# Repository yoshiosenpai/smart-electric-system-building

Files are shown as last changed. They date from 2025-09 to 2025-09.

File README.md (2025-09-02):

# Smart Electric System in Building (ESP32 + Blynk, 4× AC Bulbs, Manual Buttons)

This project demonstrates controlling **4 AC light bulbs wirelessly** using an **ESP32** and the **Blynk** app, plus **manual buttons** for local control.  
Built as a **Final Year Project (FYP) prototype** on a **wooden board**.

> ⚠️ **Prototype Only.** Not for permanent household use. Handle AC wiring with proper insulation, fuse protection, and supervision.

---

## 1) Project Overview
- **Objective:** Wi-Fi app control + **manual buttons** (like wall switches) on a demo board.
- **Core Idea:** ESP32 receives commands from Blynk **or** local button press → drives relays → toggles AC bulbs.
- **Outcome:** Two-way control with a single source of truth (ESP32 logic keeps app and buttons in sync).

---

## 2) Hardware 
1. ESP32 with expansion board  
2. 4-CH Active H/L 5V Relay Module (opto-isolated, 10A @ 250VAC)  
3. 5V 2A DC adapter  
4. LED E27 bulbs (5–10W recommended) ×4  
5. E27 bulb holders ×4  
6. **Momentary push buttons (NO)** ×4 (22mm panel type) 
7. Inline fuse (2–3A, slow blow) + fuse holder  
8. Terminal blocks, hookup wires, labels, cable ties  
9. Wooden mounting board

---

## 3) Methodology
ESP32 runs a **logic switch** model: both the **Blynk app** and **local buttons** request state changes; ESP32 **owns the ground truth** and updates **relays** and **Blynk UI** accordingly.

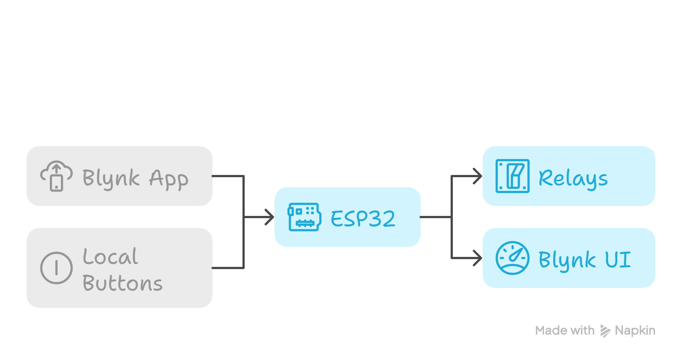
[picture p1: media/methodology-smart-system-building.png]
methodology


---

## 4) Technique & Procedure
1. **Blynk Setup**
   - Create a device/template and 4 **Switch** widgets bound to **V0–V3** (0/1).
2. **Wiring (Low Voltage)**
   - ESP32 GPIO16..19 → Relay IN1..IN4  
   - **Buttons (momentary NO)**: one side → ESP32 GPIO (e.g., 21/22/23/25), other side → **GND** (use `INPUT_PULLUP`).
   - Share **GND** between ESP32, relay board, and 5V adapter.
3. **Wiring (Mains)**
   - **Live** → **Fuse** → Relay **COM1..COM4** (bridged).  
   - Relay **NO1..NO4** → Bulbs **Live**.  
   - **Neutral** → common neutral bus to bulbs.
4. **Firmware**
   - On Blynk `V0–V3` write → set state, drive relay, reflect to app.
   - On **button press** → **toggle** channel state (debounced), drive relay, reflect to app.
5. **Demo Assembly**
   - Mount parts on wooden board; route AC and DC on **separate lanes**; add big **CAUTION** label.
   - Test one channel at a time, then full system.

---

## 5) Estimated Cost (MYR, prototype)
| Item | Qty | Unit (RM) | Subtotal (RM) |
|---|-----|---|---|
| ESP32 + Expansion Bd. | 1 | 40 | 40 |
| 4-CH Relay Module | 1 | 13 | 13 |
| 5V/2A Adapter | 1 | 14 | 14 |
| LED Bulbs (5–10W) | 4 | 7 | 28 |
| Bulb Holders | 4 | 7 | 28 |
| Momentary Buttons (NO)| 4 | 6 | 24 |
| Fuse + Holder | 1 | 26 | 26 |
| Wires, board, misc. | — | 30 | 30 |
| **Total (approx.)** | | | **204** |

---

## 6) Specifications
- **Controller:** ESP32 (Wi-Fi, Blynk IoT)  
- **Manual Control:** 4× momentary NO buttons (GPIO with `INPUT_PULLUP`)  
- **Relays:** 4 channels, opto-isolated, 10A @ 250VAC (mechanical)  
- **Loads:** 4× LED bulbs (5–10W each)  
- **Power:** 5V 2A DC adapter (ESP32 + relay coils)  
- **Prototype:** Wooden board mounting with labeled channels and safety fuse

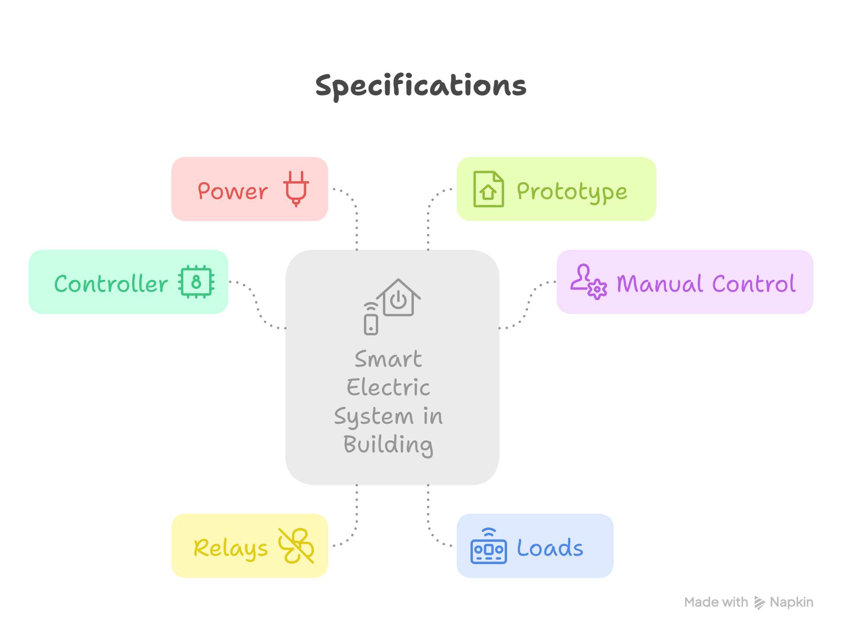
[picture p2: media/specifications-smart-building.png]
Specifications


---

## 7) Wiring Tables

### 7.1 Low-Voltage (ESP32, Buttons, Relays, 5V)
| Component | Pin / Terminal  | Connects To | Notes |
|---|---|---|---|
| ESP32 | 5V / VIN | Relay VCC & 5V adapter +  | Power to relay board |
| ESP32 | GND | Relay GND & 5V adapter –  | Common ground |
| ESP32 | GPIO16 | Relay IN1 | Channel 1 control |
| ESP32 | GPIO17 | Relay IN2 | Channel 2 control |
| ESP32 | GPIO18 | Relay IN3 | Channel 3 control |
| ESP32 | GPIO19 | Relay IN4 | Channel 4 control |
| Button 1 (NO) | One leg | ESP32 **GPIO21** | Set `INPUT_PULLUP` |
| | Other leg | ESP32 **GND** | Press → LOW |
| Button 2 (NO) | One leg | ESP32 **GPIO22** | 〃 |
| | Other leg | ESP32 **GND** | 〃 |
| Button 3 (NO) | One leg | ESP32 **GPIO23** | 〃 |
| | Other leg | ESP32 **GND** | 〃 |
| Button 4 (NO) | One leg | ESP32 **GPIO25** | 〃 |
| | Other leg | ESP32 **GND** | 〃 |

### 7.2 Mains (Fuse, Relays, Bulbs)
| Component | Pin / Terminal | Connects To | Notes  |
|---|---|---|---|
| AC **Live** | — | **Fuse** → Relay **COM1–4**  | Bridge COM1–COM4 after fuse |
| Relay CH1 | **NO1** | Bulb 1 **Live** | Switched live |
| Relay CH2 | **NO2** | Bulb 2 **Live** | 〃 |
| Relay CH3 | **NO3** | Bulb 3 **Live** | 〃 |
| Relay CH4 | **NO4** | Bulb 4 **Live** | 〃 |
| AC **Neutral** | — | Bulbs Neutral (common bus) | Direct |
| Earth (if any) | — | As required by fixtures | Safety/metal parts |

---

## 8) How It Works
1. ESP32 boots, connects to Wi-Fi and Blynk.  
2. **Blynk Switch (V0–V3)** or **Button press** requests a channel toggle.  
3. ESP32 updates the **channel state**, drives the **relay**, and **reflects state** back to the Blynk UI.  
4. Bulbs turn ON/OFF via **NO** contacts switching the **Live** conductor.

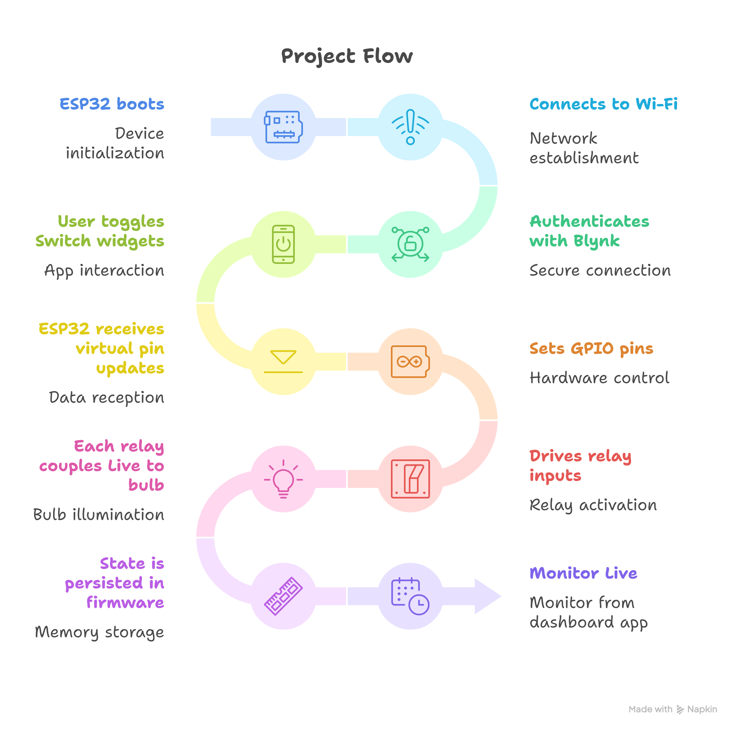
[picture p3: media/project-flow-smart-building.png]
Project-Flow


---

## 9) Firmware Scaffold
- Configure pins: `RELAY[4] = {16,17,18,19}`, `BUTTON[4] = {21,22,23,25}`  
- Set buttons `INPUT_PULLUP`, debounce ~100–150 ms  
- On Blynk write → set state + drive relay + `virtualWrite()`  
- On button press → **toggle** state + drive relay + `virtualWrite()`  
(See `/firmware/main.cpp` for the full example.)

---

## 10) Safety Checklist
- **Inline fuse** on Live before relay COM bridge.  
- Keep AC and DC physically separated on the board.  
- Use terminal blocks/heatshrink for all mains joints.  
- Label channels and add a visible **CAUTION: 230V/120V AC** sign.  
- Never touch the board while powered.

---

## 11) License
Licensed under the **MIT License** — see [`LICENSE`](./LICENSE).

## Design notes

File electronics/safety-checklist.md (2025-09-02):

# Safety Checklist — Smart Electric System (FYP Prototype on Wooden Board)

> ⚠️ **DANGER: MAINS VOLTAGE (230 VAC / 120 VAC).** This prototype is for demonstration only and is **not** a certified household installation. Work under supervision, use proper tools/PPE, and never touch the board while energized.

## 0) Scope & Assumptions
- Use case: ESP32 controls 4 relays to switch LED bulbs (5–10 W each).
- Mounting: Exposed components on a **wooden board** with clear AC vs DC lanes.
- Architecture: **Option A (logic switch)** — momentary buttons to ESP32 GPIO; no mains switching by the buttons.

---

## 1) Personal Protective Equipment (PPE)
- [ ] Safety glasses
- [ ] Insulated screwdrivers
- [ ] Closed shoes, no metal jewelry/watches
- [ ] One-hand rule when probing live (keep other hand away)

---

## 2) Standards & Good Practice (Educational Context)
- [ ] **RCD/GFCI** (residual current device) protected outlet used for demos
- [ ] **Labeling**: “⚠️ MAINS VOLTAGE — DEMO ONLY” clearly visible
- [ ] **Supervision**: A qualified person reviews the wiring before first power-up

---

## 3) Parts Ratings & Selection
- [ ] Relay module rated **≥10 A @ 250 VAC**, opto-isolated inputs
- [ ] LED bulbs **≤10 W** each, non-smart (low inrush)
- [ ] Inline **fuse** on Live input: **2–3 A slow-blow** (for 4× LED bulbs)
- [ ] **Mains wire**: min **0.75 mm²** (≈ AWG 18) copper, heat-resistant insulation
- [ ] Low-voltage wires: properly sized, flexible, not frayed
- [ ] Power adapter: **5 V / 2 A** minimum, reputable brand

---

## 4) Layout & Segregation (Board Build)
- [ ] **Separate lanes**: AC on one side, DC/logic on the other (clear visual gap)
- [ ] Keep **≥10 mm** clearance between AC and DC runs (no crossovers)
- [ ] Relay board mounted so **AC terminals face AC lane**, **logic pins face DC lane**
- [ ] Cable management: clips/zip ties; no loose loops near hot parts
- [ ] Heat sources (bulbs, resistors) away from plastic or wood edges

---

## 5) Wiring Rules (Color, Termination, Strain Relief)
- [ ] **Color code**: Brown=Live, Blue=Neutral, Green/Yellow=Earth (or local standard)
- [ ] **Live path**: Wall → **Fuse** → Bridge to **COM1–COM4** → **NO1–NO4** → Bulb Lives
- [ ] **Neutral**: Direct neutral bus to all bulbs (never through relay)
- [ ] **Earth**: Pass through to any earthed metal parts/sockets (if used)
- [ ] All AC joints via **barrier terminal blocks** (no twisted/bare joins)
- [ ] Heatshrink or insulated ferrules on exposed conductors
- [ ] **Strain relief** on mains inlet (gland or clamp)

---

## 6) Low-Voltage (ESP32, Buttons, Relay Inputs)
- [ ] Common **GND** between ESP32, relay board, and 5 V adapter
- [ ] ESP32 → Relay IN1..IN4: short, tidy, not bundled with AC
- [ ] Buttons: **momentary NO**; one leg to GPIO (21/22/23/25), other to **GND**
- [ ] Firmware uses `INPUT_PULLUP`; press = **LOW**
- [ ] No low-voltage wire runs under AC terminals

---

## 7) Pre-Power Electrical Checks (Multimeter)
- **Continuity (power OFF, unplugged):**
  - [ ] **Live** does **not** short to **Neutral** or **Earth**
  - [ ] **ESP32 GND** has no continuity to AC Live/Neutral/Earth
- **Polarity:**
  - [ ] Fuse is on **Live** only (not on Neutral)
  - [ ] COMs are bridged **after** the fuse (not before)
- **Relay logic:**
  - [ ] With ESP32 unpowered, **NO** contacts are open (bulbs cannot energize)

---

## 8) First Power-On (Low Voltage Only)
- [ ] Power **5 V adapter** only; ESP32 boots
- [ ] Blynk connects; toggling V0–V3 moves **only** relay LEDs/clicks
- [ ] Buttons toggle channels once (no chatter); serial logs OK
- [ ] No unexpected heating or smell at relay board

---

## 9) Mains Bring-Up (Stepwise)
- [ ] Connect **one** bulb to CH1; verify wiring again
- [ ] Power mains via **RCD/GFCI** extension
- [ ] Toggle CH1: bulb ON/OFF cleanly; no flicker
- [ ] Measure current (optional) — consistent with bulb rating
- [ ] Repeat for CH2–CH4 one at a time, then all together
- [ ] 15–30 min **soak test** with all ON: relay area <~**60 °C** (touch-safe guideline)

---

## 10) Functional Safety Behaviors
- [ ] **Default OFF** at boot (all relays inactive)
- [ ] **Loss of Wi-Fi**: buttons still work; no random toggles
- [ ] **Recovery**: Blynk sync updates UI to current states
- [ ] **Emergency stop**: mains plug accessible, RCD test button known

---

## 11) What **Not** To Do
- [ ] Do **not** leave prototype powered **unattended**
- [ ] Do **not** expose **bare AC** terminals (always use barrier blocks/heatshrink)
- [ ] Do **not** route AC over/under the ESP32 or logic area
- [ ] Do **not** let wires rest on hot bulbs/lamps

---

## 12) Documentation Photos (for FYP Report)
- [ ] Full board photo with AC vs DC lanes labeled
- [ ] Close-ups: fuse placement, terminal blocks, relay outputs
- [ ] Wiring diagram/table included in README
- [ ] Short demo: button press → bulb ON/OFF; app sync

---

## 13) Sign-off (Before Public Demo)
| Item | Pass/Fail | Initials | Date |
|---|---|---|---|
| PPE & RCD in place | | | |
| AC/DC segregation & labeling | | | |
| Fuse on Live; polarity correct | | | |
| No exposed live parts | | | |
| Low-voltage tests passed | | | |
| Single-channel AC test passed | | | |
| Four-channel AC test passed | | | |
| 30-min soak test passed | | | |

---

## 14) Risk Snapshot (Top Hazards & Mitigations)
- **Electric shock (contact with live parts)** → Barrier terminals, heatshrink, RCD, clear labels, supervision  
- **Short circuit / overheating** → Inline fuse on Live, correct wire gauge, tidy routing, soak test  
- **Logic/AC cross-talk** → 10+ mm clearance, no shared bundles, opto-isolated relays  
- **Operational misuse** → Default-OFF at boot, emergency unplug accessible, demo script rehearsed

---

**Reminder:** This checklist supports educational safety. It does **not** replace national electrical codes or compliance standards.

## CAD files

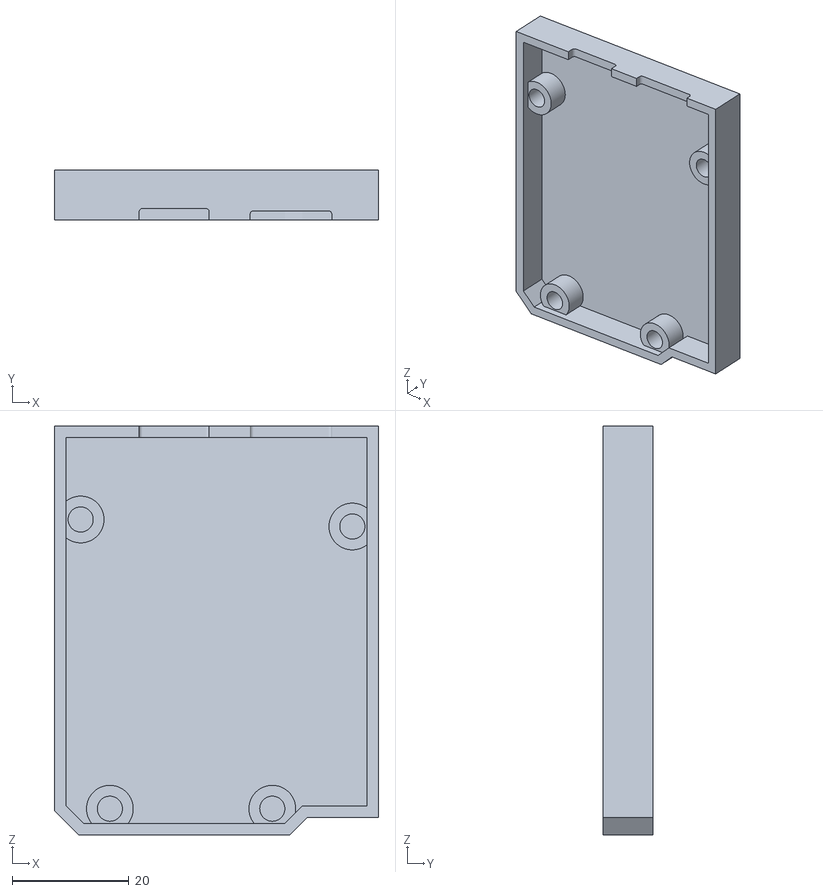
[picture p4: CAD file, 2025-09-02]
hardware/ESP32_Adapter-Base.stl
55.5 x 8.60 x 70.0

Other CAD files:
hardware/ESP32_Adapter-Base_A.stl
hardware/ESP32_Adapter_A.FCStd
hardware/ESP32_Adapter.FCStd

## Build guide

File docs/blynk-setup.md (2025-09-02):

# Blynk Setup (ESP32 + 4 Channels)

This guide links your ESP32 to the Blynk app, with 4 virtual switches (V0–V3) that control 4 relays. It matches the Arduino sketch in this repo.

---

## 1) Create Template & Device (Blynk Console)
1. Sign in to **Blynk Console** (web).
2. **Create Template**
   - Template Name: `Smart Electric System`
   - Hardware: `ESP32`
   - Connection: `WiFi`
3. **Create Datastreams (4x)**
   - For each `V0`, `V1`, `V2`, `V3`:
     - **Type:** Virtual Pin  
     - **Data Type:** Integer  
     - **Min/Max:** 0 / 1  
     - **Default:** 0  
     - **Permissions:** Read & Write  
4. **Save** the template.
5. **Create Device** from this template (assign it to your account).

> Grab these from **Device Info**:  
> - `BLYNK_TEMPLATE_ID`  
> - `BLYNK_TEMPLATE_NAME` (optional for display)  
> - `BLYNK_AUTH_TOKEN`  
> Put them in your Arduino sketch.

---

## 2) Build the Mobile Dashboard (Blynk App)
1. Open the **Blynk mobile app** → log in with the same account.
2. Your device should appear; open it.
3. Add **4 × Switch** widgets:
   - Switch #1 → Datastream `V0`
   - Switch #2 → Datastream `V1`
   - Switch #3 → Datastream `V2`
   - Switch #4 → Datastream `V3`
4. (Optional) Add **Labels** like “Bulb 1…4”.

---

## 3) Matching the Arduino Sketch
The provided sketch expects:
- **Relays:** GPIO `16/17/18/19` → Relay `IN1..IN4`
- **Buttons (momentary NO):** GPIO `21/22/23/25` → GND (use `INPUT_PULLUP`)
- **Virtual pins:** `V0..V3`
- **Active-LOW relays:** `RELAY_ACTIVE_LOW = true` (flip if your board is active-HIGH)

On connection, the code does:
```cpp
Blynk.syncVirtual(V0, V1, V2, V3);

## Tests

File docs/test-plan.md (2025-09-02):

# Test Plan — Smart Electric System (ESP32 + Blynk + Buttons)

Scope: Verify Option-A logic (ESP32 as source of truth), safety basics, and demo readiness on a wooden board.

---

## 1) Test Environment
- Low-voltage: ESP32 + 4-ch relay board + 5V/2A adapter
- Inputs: 4 × momentary NO buttons (to GND)
- Loads: 4 × LED bulbs (5–10 W), E27 holders
- AC: Fused Live → Relay COM bridge; NO → Bulb Lives; Neutral bus
- Tools: Serial Monitor (115200), multimeter (voltage/current), timer/stopwatch
- Network: 2.4 GHz Wi-Fi or phone hotspot

---

## 2) Acceptance Criteria (summary)
- **Connectivity:** ESP32 connects to Wi-Fi & Blynk within 30 s.
- **Control:** Each channel toggles via **App** and **Button**; update reflected in both within 300 ms.
- **Default State:** On power-up, all channels **OFF** (relays inactive) until commanded.
- **Debounce:** Single press → single toggle (no chatter).
- **Safety:** Fuse inline on Live; AC and DC wiring clearly separated and insulated.
- **Soak:** 30-minute ON test: no excessive heating or intermittent behavior.

---

## 3) Functional Tests

### 3.1 Low-Voltage Bring-Up
| Step | Action | Expected |
|-----:|---|---|
| 1 | Power ESP32 + relays only (no AC) | Board powers; no relays latched |
| 2 | Open Serial Monitor | Wi-Fi + Blynk connect messages |
| 3 | Press Button 1 | Serial shows `[CH1] -> ON/OFF`; Relay 1 clicks |
| 4 | Toggle V0 in app | Relay 1 clicks; Serial reflects state; app mirrors |
| 5 | Repeat for CH2–CH4 | All pass |

### 3.2 App–Button Consistency
| Step | Action | Expected |
|-----:|---|---|
| 1 | Turn CH1 ON in app | Relay ON; app shows ON |
| 2 | Press Button 1 once | Relay toggles OFF; app flips to OFF |
| 3 | Press Button 1 twice (slow) | Two toggles; app matches each |
| 4 | Long-press Button 1 | **One** toggle only (debounce ok) |

### 3.3 Power Cycle Behavior
| Step | Action | Expected |
|-----:|---|---|
| 1 | Set CH1=ON, CH2=OFF, CH3=ON, CH4=OFF | States set |
| 2 | Power cycle ESP32 | All relays default **OFF** at boot |
| 3 | After Blynk connect | `syncVirtual` aligns app and device (device keeps OFF until commanded) |

> Note: This prototype defaults **OFF** for safety. Document this in your report.

---

## 4) High-Voltage (AC) Tests — With Caution
**Pre-check:** Fuse installed; terminals insulated; clear AC/DC separation; supervisor present.

### 4.1 Single-Channel AC Test
| Step | Action | Expected |
|-----:|---|---|
| 1 | Wire CH1 only to bulb | Wiring checked |
| 2 | Apply AC | No sparks/smell; bulb OFF |
| 3 | Toggle V0 (or Button 1) | Bulb ON/OFF cleanly; no flicker |
| 4 | Measure current | Matches bulb rating; relay coil still cool |

### 4.2 Four-Channel AC Test
| Step | Action | Expected |
|-----:|---|---|
| 1 | Wire all 4 bulbs | Wiring checked |
| 2 | Turn all ON | All bulbs ON; adapter/relays stable |
| 3 | Turn all OFF | All bulbs OFF |

---

## 5) Soak & Thermal
- **Test:** Keep all four bulbs ON for **30 minutes**.
- **Observe:** No random toggles; relay board temperature acceptable (coil area ideally < ~60 °C).  
- **Record:** Ambient temp, any anomalies.

---

## 6) Network Resilience
| Step | Action | Expected |
|-----:|---|---|
| 1 | Disconnect Wi-Fi/hotspot | App shows offline; **buttons still work** |
| 2 | Reconnect Wi-Fi | Device reconnects; app syncs to current states within a few seconds |

---

## 7) Documentation Artifacts to Capture
- Photos of board layout (AC lane vs DC lane), fuse placement, labels
- Short video: Button press → app updates; App toggle → relay click → bulb ON
- Serial logs during tests (copy snippets)
- Cost table + final BOM links

---

## 8) Test Log Template

| Date | Tester | Test Case ID | Result (P/F) | Notes / Fixes |
|---|---|---|---|---|
| | | LV-01 | | |
| | | LV-02 | | |
| | | AC-01 | | |
| | | AC-02 | | |
| | | SOAK-01 | | |
| | | NET-01 | | |

---

## 9) Risks & Mitigations
- **Mains safety:** Always fuse Live; insulate joints; never touch while powered.  
- **Relay logic inverted:** Flip `RELAY_ACTIVE_LOW`.  
- **Button bounce:** Increase `DEBOUNCE_MS`.  
- **Wi-Fi drop:** Buttons still work; state sync on reconnect.

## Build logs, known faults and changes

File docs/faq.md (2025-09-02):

---

### `docs/faq.md`

```markdown
# FAQ — Smart Electric System (FYP Prototype)

## General
**Q: Is this safe for permanent home use?**  
A: No. This is a **demo prototype** on a wooden board. It is not certified for household installation.

**Q: Why do we use Blynk “Virtual Pins” instead of Digital Pins?**  
A: Virtual Pins decouple app UI from hardware pins, making sync and logic handling easier (e.g., buttons + app + debouncing).

---

## Connectivity
**Q: ESP32 won’t connect to Wi-Fi.**  
- Use **2.4 GHz** SSID (no 5 GHz).  
- Check SSID/PASS spelling; avoid special characters.  
- Try a phone hotspot for demo stability.

**Q: Blynk stays offline.**  
- Verify `BLYNK_AUTH_TOKEN`.  
- Log into the **same Blynk region** on Console and App.  
- Ensure the device is created from the **same template** with V0–V3.

---

## Relays & Buttons
**Q: Relays click ON when I expect OFF.**  
- Your module might be active-HIGH. Set `RELAY_ACTIVE_LOW = false;`

**Q: Buttons don’t toggle reliably.**  
- Confirm wiring: **GPIO ↔ Button ↔ GND**; use `INPUT_PULLUP`.  
- Increase debounce: `DEBOUNCE_MS` to 150–200 ms.

**Q: Why momentary (NO) buttons, not latching switches?**  
- With Option A, ESP32 is the “logic switch”. Momentary inputs produce clean events; firmware maintains the true state and syncs to Blynk.

---

## Power & Safety
**Q: What fuse rating should I use?**  
- Inline fuse on **Live**; typical **2–3 A slow-blow** for 4 × 5–10 W LED bulbs (low current). Adjust for your local mains and load.

**Q: The relay board gets warm. Is that normal?**  
- Mild warmth is okay. Run a **15–30 min soak test**; keep relay coil area <~60 °C. Improve spacing/ventilation on the board.

---

## Features & Extensions
**Q: Can I add schedules/automation?**  
- Yes, use Blynk Automation or add firmware timers (e.g., `BlynkTimer`).

**Q: Can I see the *actual* lamp state if someone changes mains?**  
- That’s **Option B** (AC sensing). For FYP safety, we stick to Option A. You can demo Option B on one channel with an isolated AC sensor if required.

**Q: Can I add OTA updates?**  
- Yes (ArduinoOTA or AsyncElegantOTA). Not required for this FYP, but nice bonus.

---

## Presentation Tips
- Show both **App control** and **Button control**.  
- Keep AC and DC lanes separated; use big **CAUTION: 230V/120V AC** label.  
- Bring a short **demo script** and a **multimeter** for current checks.

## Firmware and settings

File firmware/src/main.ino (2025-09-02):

/*
  Smart Electric System in Building (Option A: Logic Switch)
  Arduino IDE version
  - ESP32 + Blynk control for 4 relays (AC bulbs)
  - 4 local momentary buttons (NO) for manual toggle
  - Debounce + edge trigger
  - Keeps Blynk UI in sync with real state

  Low-voltage wiring:
    RELAY CH1..CH4: ESP32 GPIO16,17,18,19 -> Relay IN1..IN4
    BUTTON 1..4:   One leg -> ESP32 GPIO21,22,23,25 ; Other leg -> GND (INPUT_PULLUP)

  Mains:
    AC Live -> Fuse -> Relay COM1..COM4 (bridged)
    Relay NO1..NO4 -> Bulb1..Bulb4 Live
    Neutral -> common neutral bus

  Code by Solehin Rizal
*/
